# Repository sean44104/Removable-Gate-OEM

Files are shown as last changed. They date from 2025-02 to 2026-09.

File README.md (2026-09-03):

# Removable-Gate-OEM

Removable Gate OEM is a project [based on my previous work](https://github.com/sean44104/Removable-Gate-GCC) designed to bring the removable gate system to OEM Gamecube Controller shells in the form of a small DIY kit

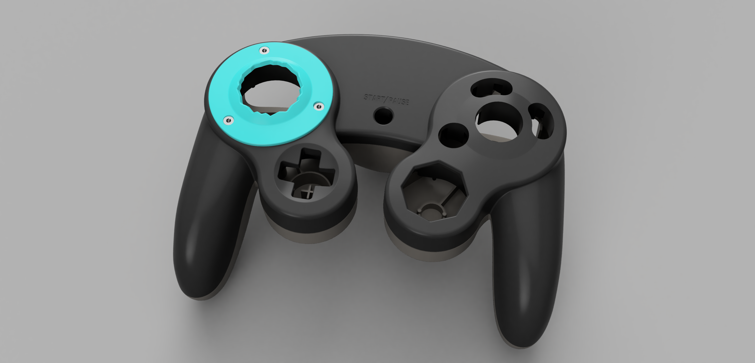
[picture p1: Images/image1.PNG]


This release contains STL, STEP, and F3D files for each part of the project. The STLs are high resolution and ready to be resin printed. You can import the F3D file into fusion360, or the STEP files into any other CAD program you like to make changes to the design as you see fit! The files feature 5 unique gateplate designs, each with their own different number of notches for you to experiment with. Additionally, the files also include what I call a **ThreadHolder** and a **DrillJig**. The ThreadHolder is a piece that will slide under the control stick area of the GCC front shell. It has slots inside that will hold the metal threads permanently inside of the shell. When you put a gateplate onto the front of your controller, the gateplate will screw into these threads and hold it firmly in place!

This project requires modification of the OEM Gamecube Controller front shell in order to fit and function. A section of the shell first needs to be removed, and then 3 holes need to be drilled into the shell. These holes require a 3/16 inch drill bit. The DrillJig is a piece that slides under the control stick area of the GCC, just like the ThreadHolder, and shows you exactly where to drill so that you can put the drill holes in the exact perfect spot. After you are done drilling, the DrillJig is to be removed from the controller and replaced by the ThreadHolder, the permanent piece that goes in that spot for the mod to work. You can reuse the DrillJig to drill holes in multiple controller shells. **Use the DrillJig after removing the gate area of the front shell and before installing the ThreadHolder!**

### Relevant Links:

Gateplate Screws: https://www.mcmaster.com/90236A105/

Gateplate Threads: https://www.mcmaster.com/90363A110/

Where to Purchase the 3D Printed Parts: https://jlc3dp.com

The Gateplate Screws are T6 Torx Screws. If you do not have a T6 Torx Screwdriver, [you can buy them anywhere](https://www.amazon.com/Screwdriver-TECKMAN-Controller-Mainboard-Electronic/dp/B08998GX65/ref=asc_df_B08998GX65)

YouTube Video going over the concept and explaining how the kit works with visuals:
https://youtu.be/-zyUboVVk4A

Video Build Guide: https://youtu.be/2FYZF3ZB4hE

Parametric Notch Builder Tool: https://www.printables.com/model/1191100-parametric-notch-builder-tool-for-oem-stubby-gatep

CarVac FDM File Set & Additional Parametric Gateplates: https://www.printables.com/model/1504464-oem-gamecube-controller-notched-gateplates/files

This design is based on, and uses the OEM GCC step file collection made by GearHawkStudios

### Optional PTFE Upgrade:

I have found that when using resin printed gateplates, especially with resin casted stick caps, there can be more friction on the gate against the stick than on a standard controller. I highly recommend applying a layer of PTFE tape around the neck of your stick cap. This small mod can help improve the feel of your gate and enhance the durability of your controller. 

PTFE Tape: https://www.mcmaster.com/6305A51/

Installation Guide: https://youtu.be/KtZ6UY_qpAE

### Removable Gates and Notched Gateplates
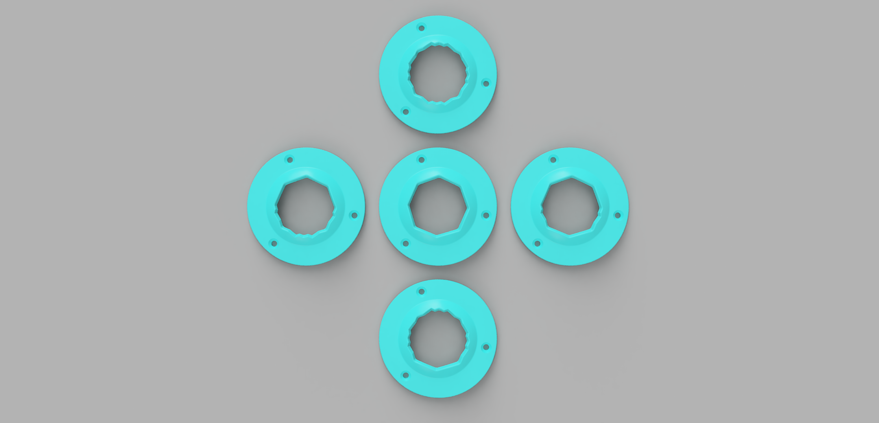
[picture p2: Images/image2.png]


### DrillJig (left) and ThreadHolder (right)
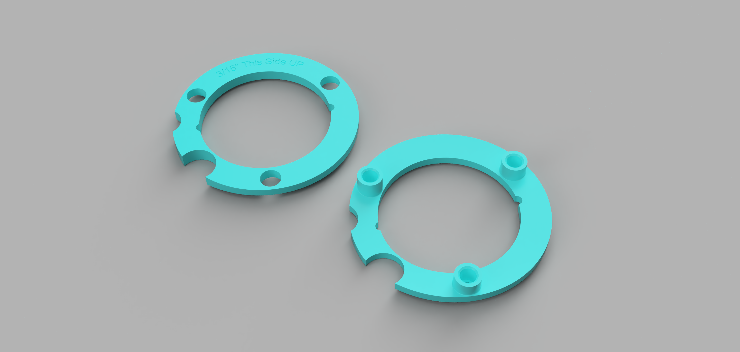
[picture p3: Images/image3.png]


### Inside View of the ThreadHolder System
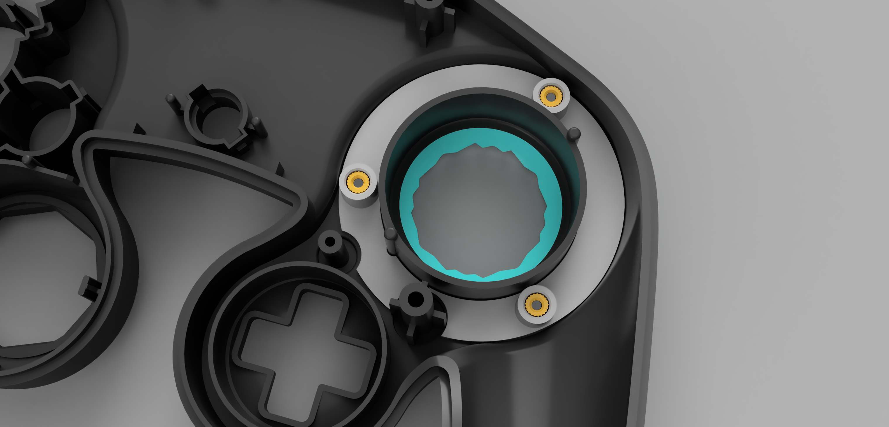
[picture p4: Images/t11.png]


# Parametric Notch Builder
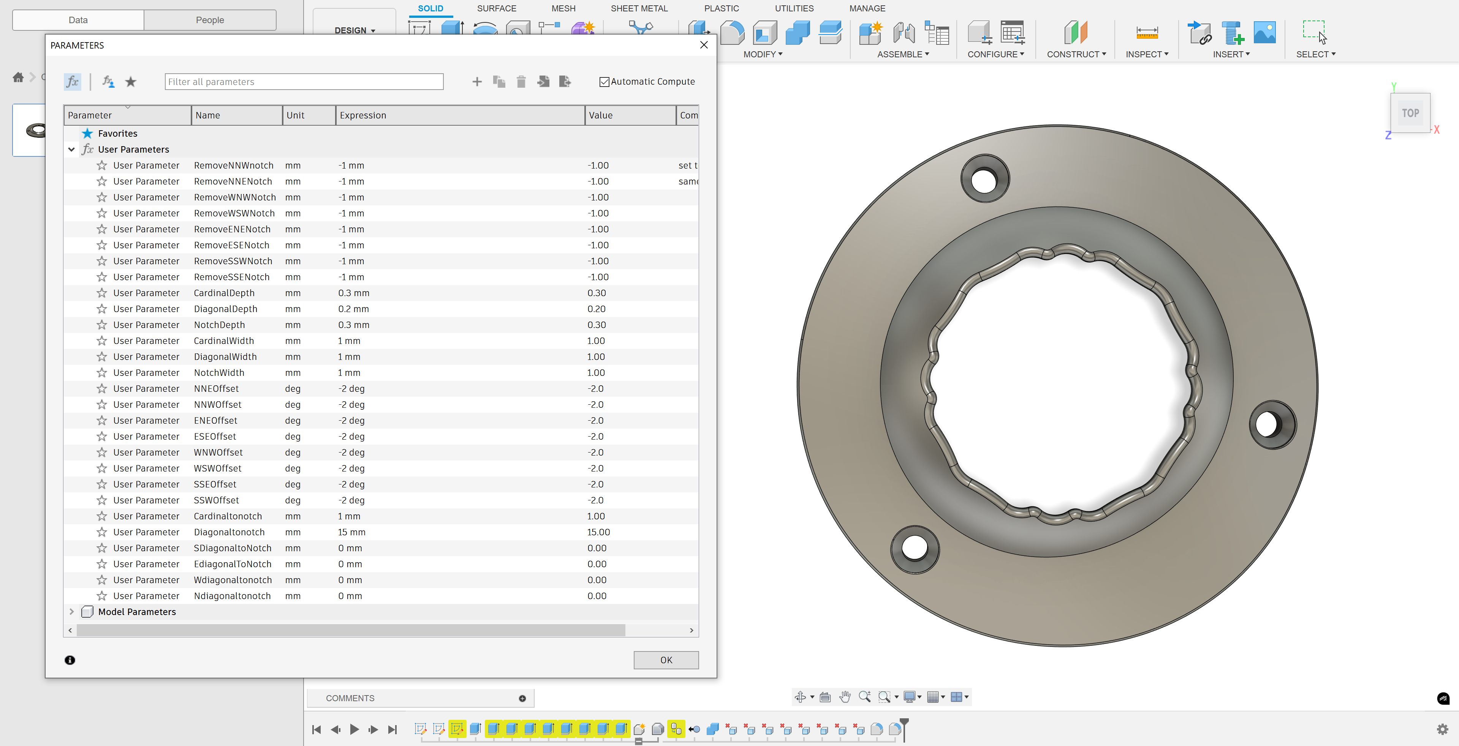
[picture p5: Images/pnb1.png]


The [Parametric Notch Builder Tool](https://www.printables.com/model/1191100-parametric-notch-builder-tool-for-oem-stubby-gatep) allows you to input values into a menu and slightly adjust the geometry of a Notched Gateplate. With this, you can remove notches, adjust notches, move notches around the gate, and adjust the overall shape and profile. This lets you get very specific with your Gateplate design and allows you to do things that are character specific on a whim.
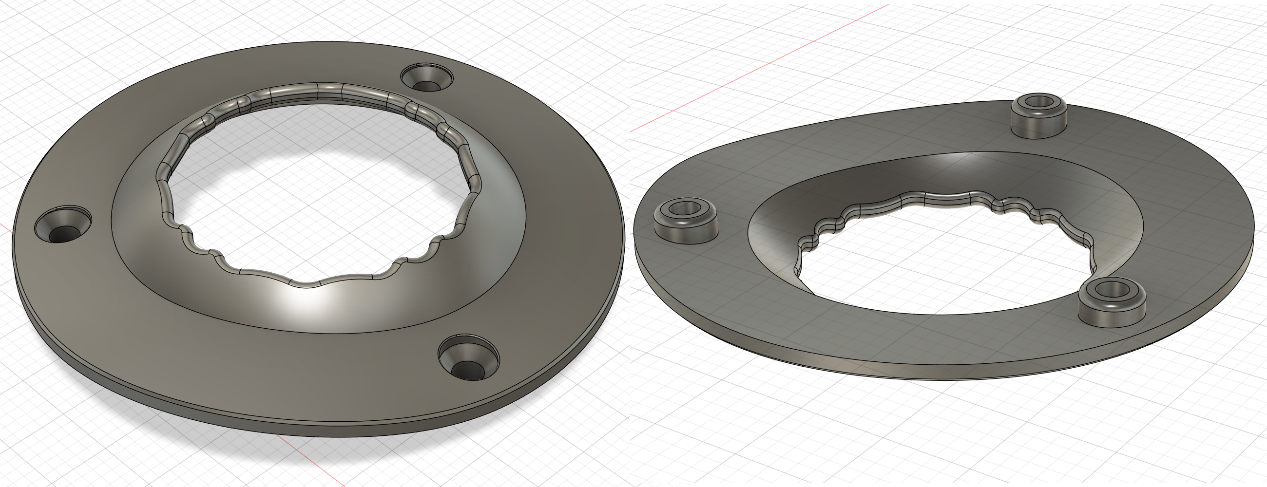
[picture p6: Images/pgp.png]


Personally, I prefer the smooth profile of the parametric notched gateplate over harsher notched gateplates included in the standard release. I have included some sample gateplates made using this tool, and I encourage you to try it out and create your own!

# Removable Gate OEM Installation Tutorial:
<details>
  <summary>Click to expand</summary>

## Step 1
The first thing you need to do is remove the gate material from the front shell. Remove the entire lifted circular section of the control stick gate, shown here in green. Cut off the entire lifted dome until it is flat with the rest of the front shell's surface. You can use a dremel to cut it off and then sand down the excess. Do not go deep into the shell, remove any of the inside, or take out the cylinder that extends down into the shell. Here is a front and side profile of what is to be removed:
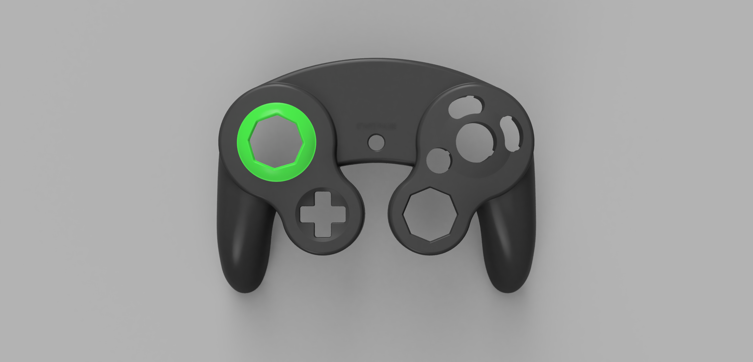
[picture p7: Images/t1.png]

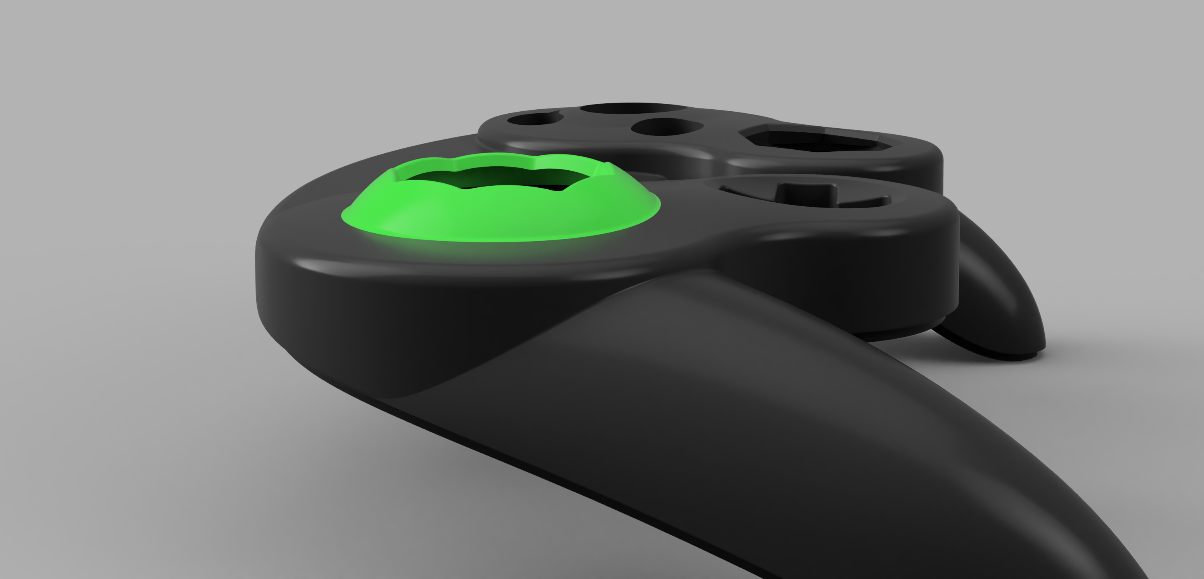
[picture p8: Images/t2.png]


**Your shell should look like this after you are finished**
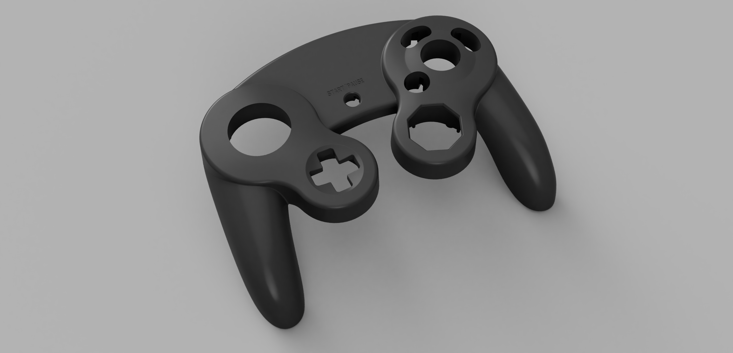
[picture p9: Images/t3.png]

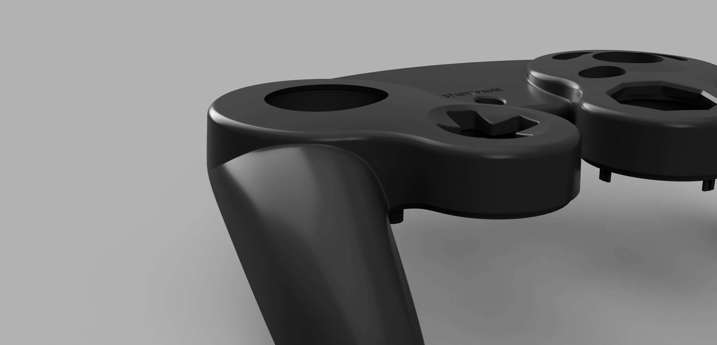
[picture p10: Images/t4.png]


## Step 2
Next, you are going to use the DrillJig. Slide the jig into the back of the front shell so that the curved side is going down into the controller and the flat side is facing up as shown. Now, use a 3/16 inch drill bit to remove the material shown here in green:
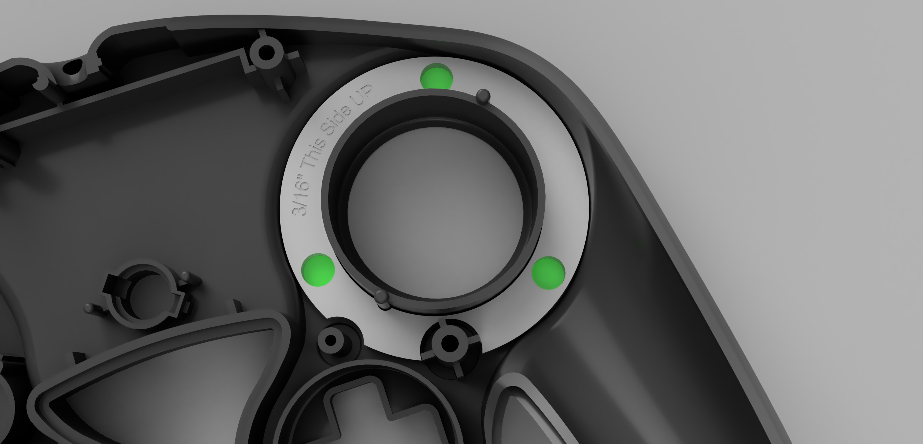
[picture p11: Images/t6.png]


Once you are finished drilling it should look like this:
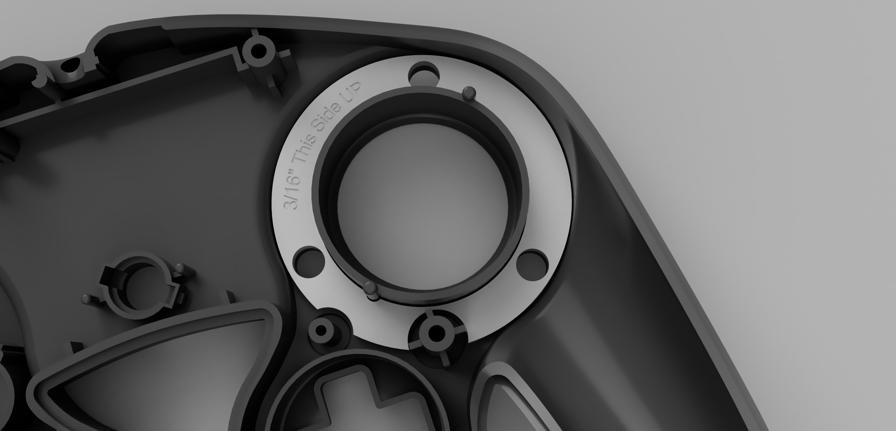
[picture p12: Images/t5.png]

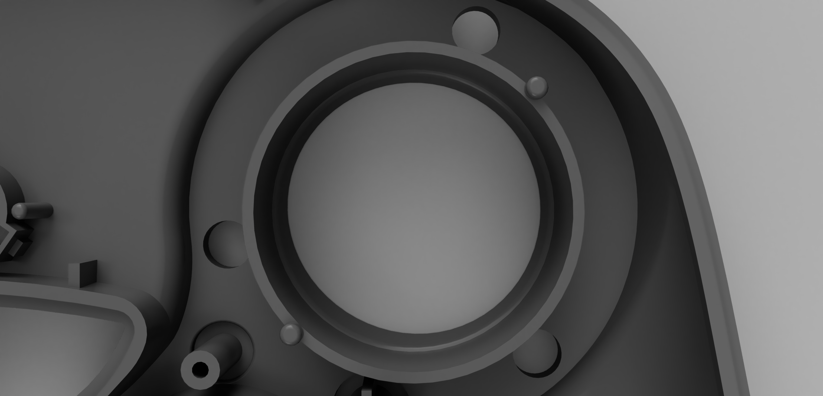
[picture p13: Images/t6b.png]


Here is a view from the other side:
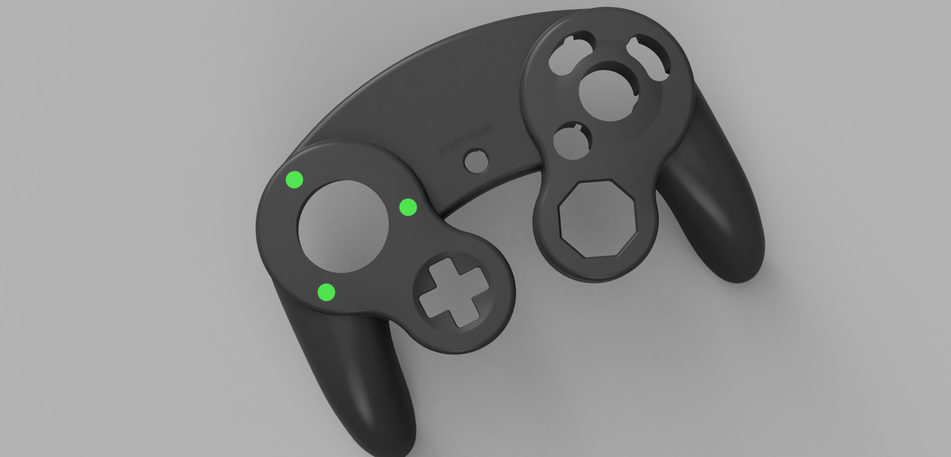
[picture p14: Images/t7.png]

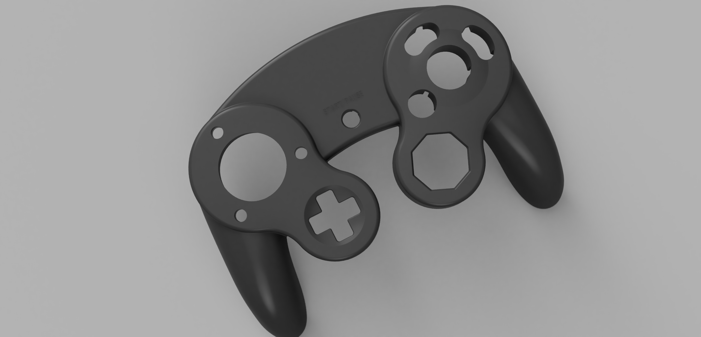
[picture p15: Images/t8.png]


## Step 3
Now, you are going to install the ThreadHolder. Remove the DrillJig from the controller shell and apply a small amount of glue to the flat top surface of the ThreadHolder. Then, you are going to slide it into the back of the front shell, just like the DrillJig, shown here:
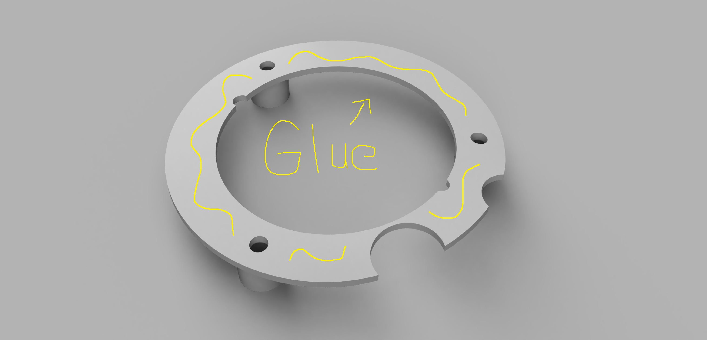
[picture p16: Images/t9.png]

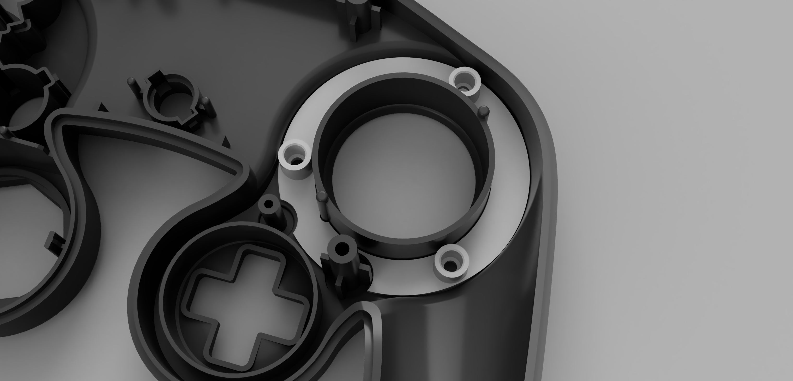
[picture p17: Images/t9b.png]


Make sure to firmly press the ThreadHolder in and push it down so that the entire piece makes good contact with the back of the controller front shell

## Step 4
Take your [thread pieces](https://www.mcmaster.com/90363a110/) and push them into the containers of the ThreadHolder until they are all the way in, as shown. This may be a tight friction fit, so you can use a screwdriver to push them in by applying pressure to the center of the thread piece.
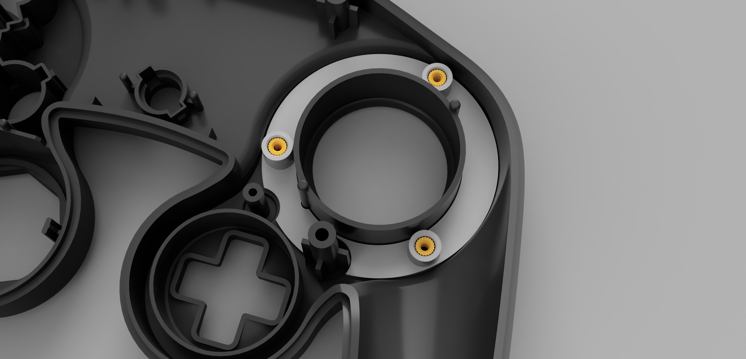
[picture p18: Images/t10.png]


These thread pieces are designed to expand out when [the screw](https://www.mcmaster.com/90236A105/) is threaded inside of them, embedding themselves into the ThreadHolder and locking them inside of there permanently. I recommend that for the first time, you put the screws in upside-down like so. This way the threads can be expanded securely and will not fall out.
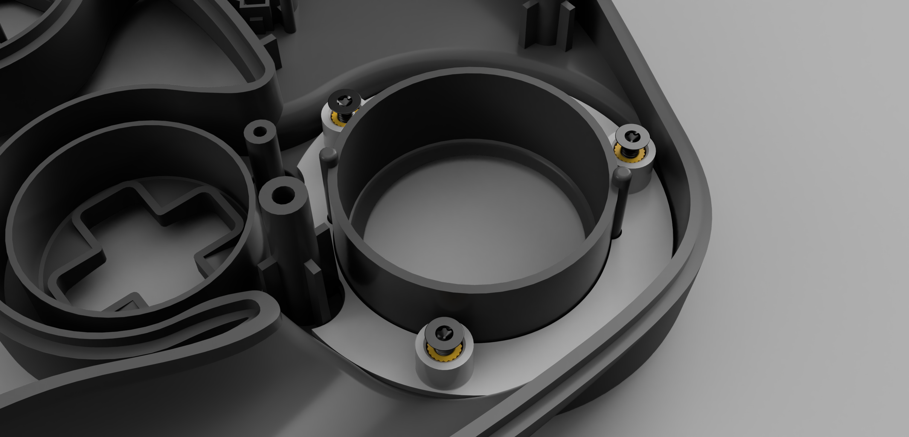
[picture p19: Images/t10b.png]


## Step 5
You are basically done now! Remove the upside-down screws from their thread pieces. The front shell is complete. You can now take a Gateplate and place it onto the front face of your Gamecube Controller front shell. It has three pegs underneath it, which will slot nicely into the holes that you drilled. Now, just insert a screw into each of the three holes on the gateplate surface and they will go through the gateplate, through the front shell, and thread into the metal inserts inside of the ThreadHolder. It will look like this when you are done and everything is fully installed:
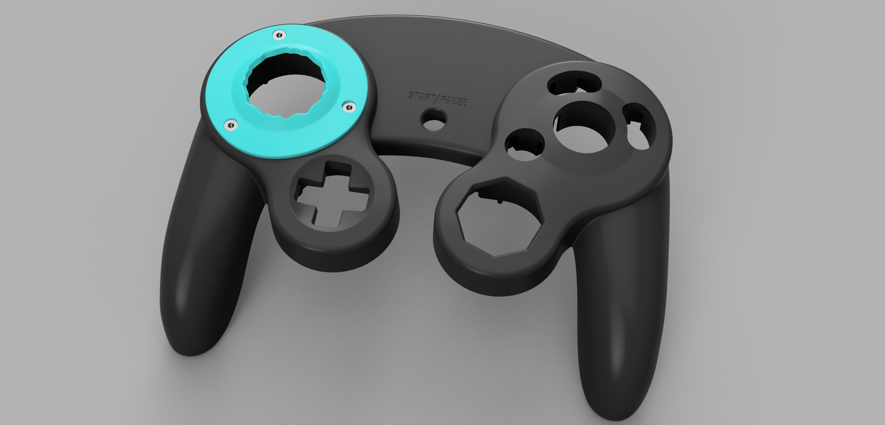
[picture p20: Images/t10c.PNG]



Now, you can assemble your controller. You will be able to remove and attach gateplates onto your controller while it is fully assembled. You do not have to take the controller apart whatsoever to remove or swap out a gateplate. Simply unscrew the Gateplate, remove the screws, and pull the Gateplate out.
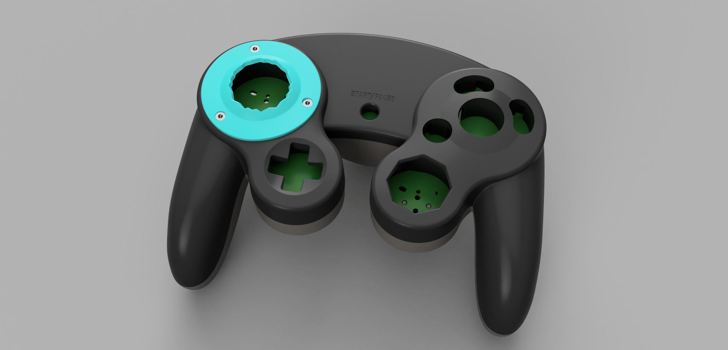
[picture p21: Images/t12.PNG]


The internal parts will stay in place and not fall out. Happy Modding!
</details>

# Optimal JLC3DP Part Settings, Prices, and Shipping:
<details>
  <summary>Click to expand</summary>

## Gateplates
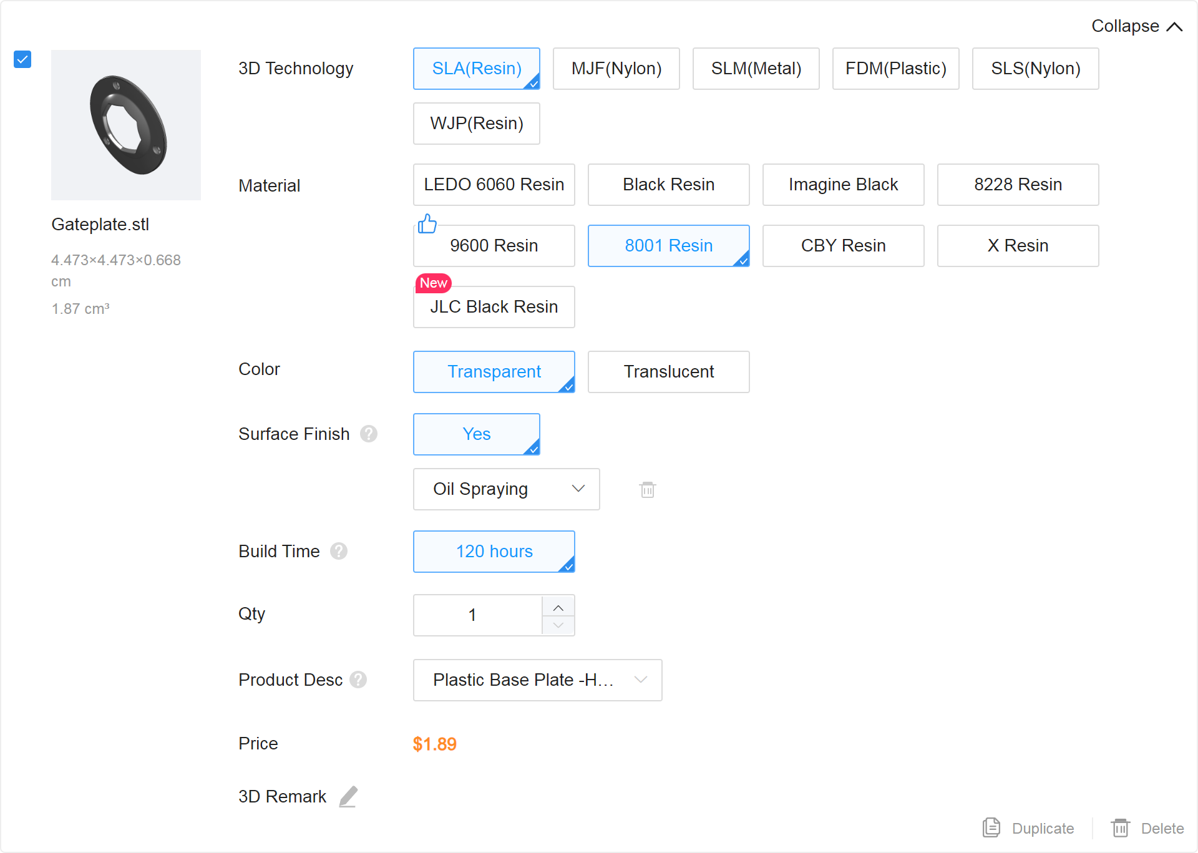
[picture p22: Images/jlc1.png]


8001 Transparent Oil Spray is the best material for the Gateplate because of its high hardness, low friction, and good dimensional stability. A Gateplate made of this material will feel the smoothest when it touches your control stick and most OEM ABS Plastic-like. It will be more consistent and have a more perfect shape than something like Black Resin. 8001 Transparent Oil Spray Resin does have an issue where it is slightly thicker than the rest of the materials. For this reason, I do not recommend it for internal parts where tolerances and clearance are a priority. But for the external Gateplate, its perfect.

## ThreadHolder
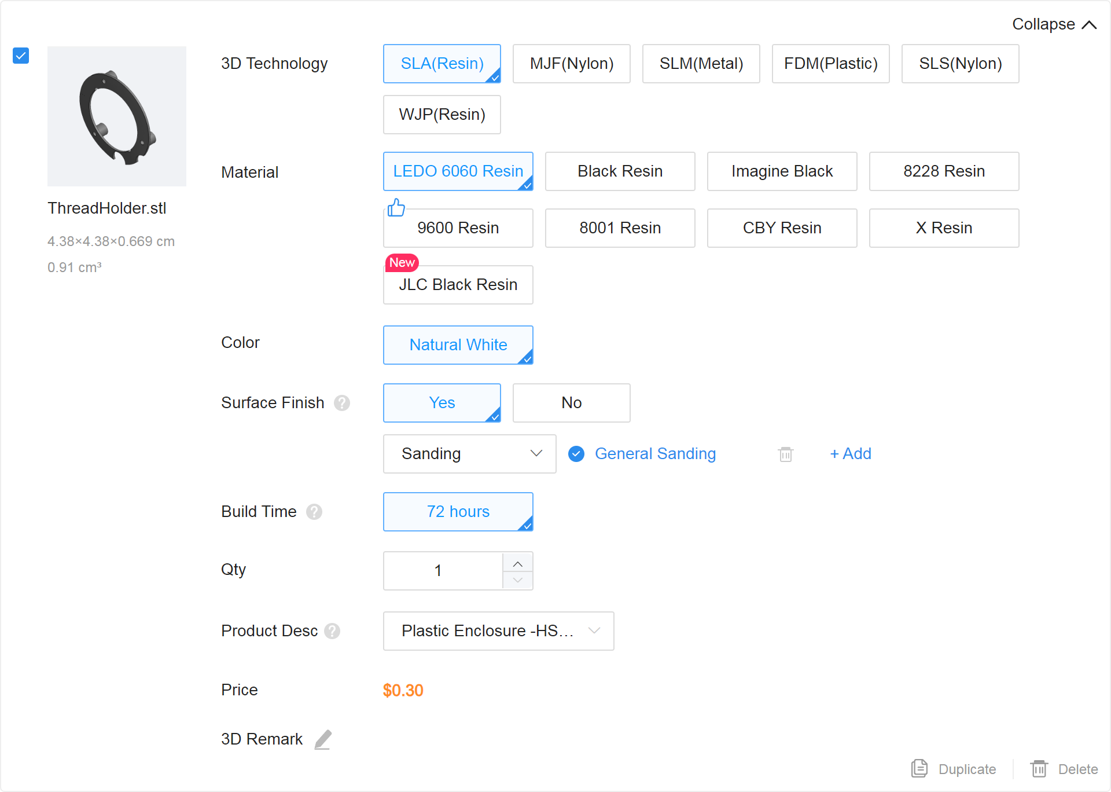
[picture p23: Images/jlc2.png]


LEDO 6060 is the least expensive resin on the website. It does not have the smoothness of 8001 Transparent Oil Spray or the highly detailed and accurate surface finish of Black Resin, but it is more dimensionally stable than Black Resin and does not have the extra thickness issue that 8001 has. For a precise part like the ThreadHolder, that also wont be seen from the outside very much at all, I believe LEDO 6060 is the best choice.

## DrillJig
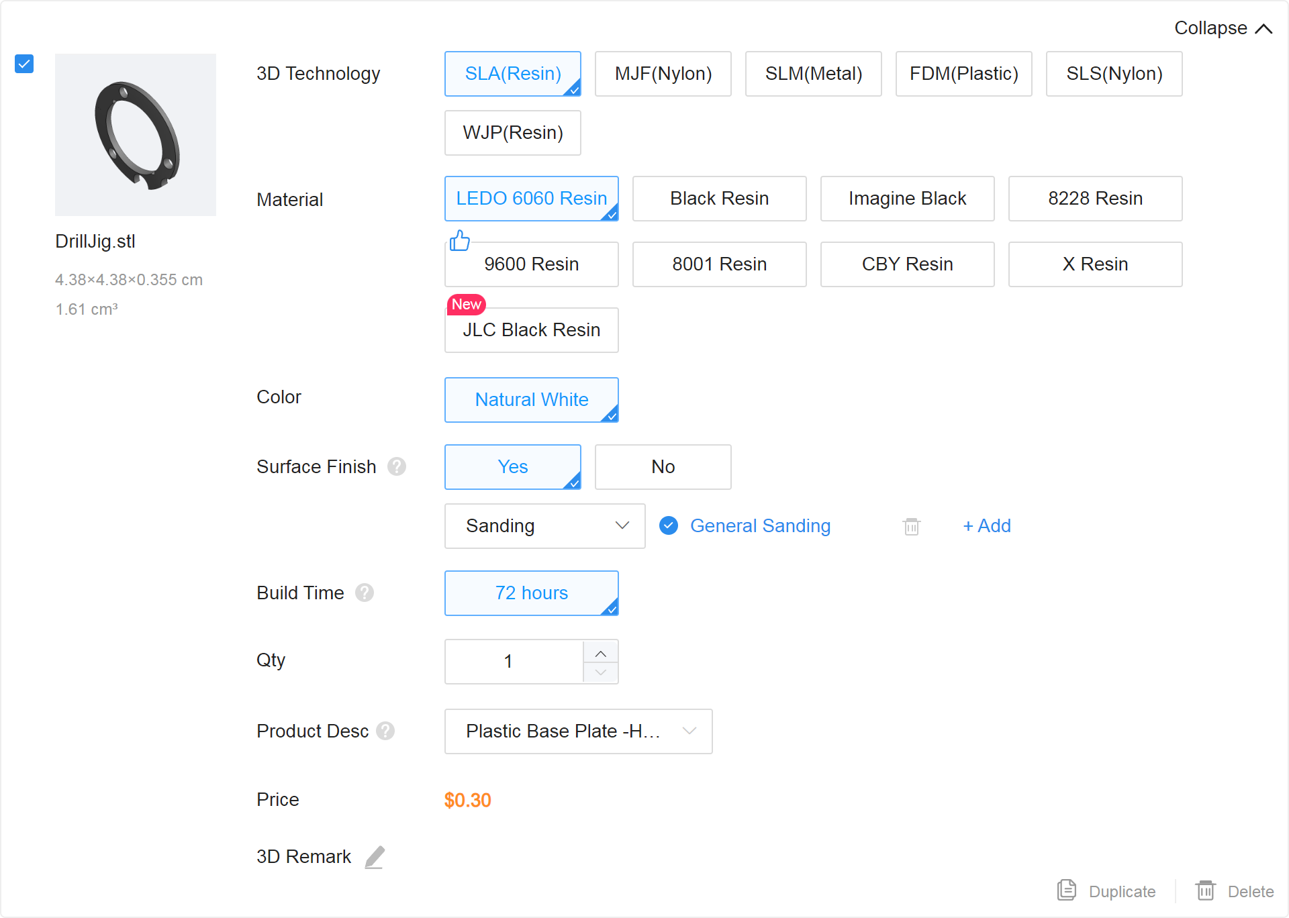
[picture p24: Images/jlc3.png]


I choose LEDO 6060 resin for the DrillJig for pretty much the same reason as I chose it for the ThreadHolder. The DrillJig is the only temporary piece in this kit. It is used to accurately drill your holes, and then it is either discarded or used again to make multiple shells. Because of this, it's material matters the least. Also, because of the DrillJig's completely flat surface, you could probably FDM print this part as well!

## Other Parts

While not explicitly part of this project, I do want to point out that *generally* the best and safest resin to print something in is actually Black Resin or JLC Black Resin. This resin type is smooth to the touch and has very high "resolution". It has a detailed, smooth, accurate surface that is much better than something like LEDO 6060. For general parts, such as buttons, shells, stick bases, or other small detailed parts, Black Resin is generally the way to go. If you want to guarantee that the part you order is MOST similar to the STL file that you designed and submitted, you should usually order parts in JLC Black Resin.

## Shipping

While you may notice that the prices for these individual parts can be very inexpensive, keep in mind that the shipping is usually where the majority of the cost is going to come from. While JLC3DP shipping can be relatively expensive, this does not mean that it is bad or that your parts will take months to get to you. From my experience, it takes about 2-3 weeks for an order to go from shipped to delivered. Usually around 10 days. Below are some prices and shipping estimates from JLC3DP. I would consider their information to be accurate. Even with the shipping cost included, you can obtain all of the 3D printed the parts needed for this kit for only about $20 - $30

<details>
  <summary>Click to expand</summary>

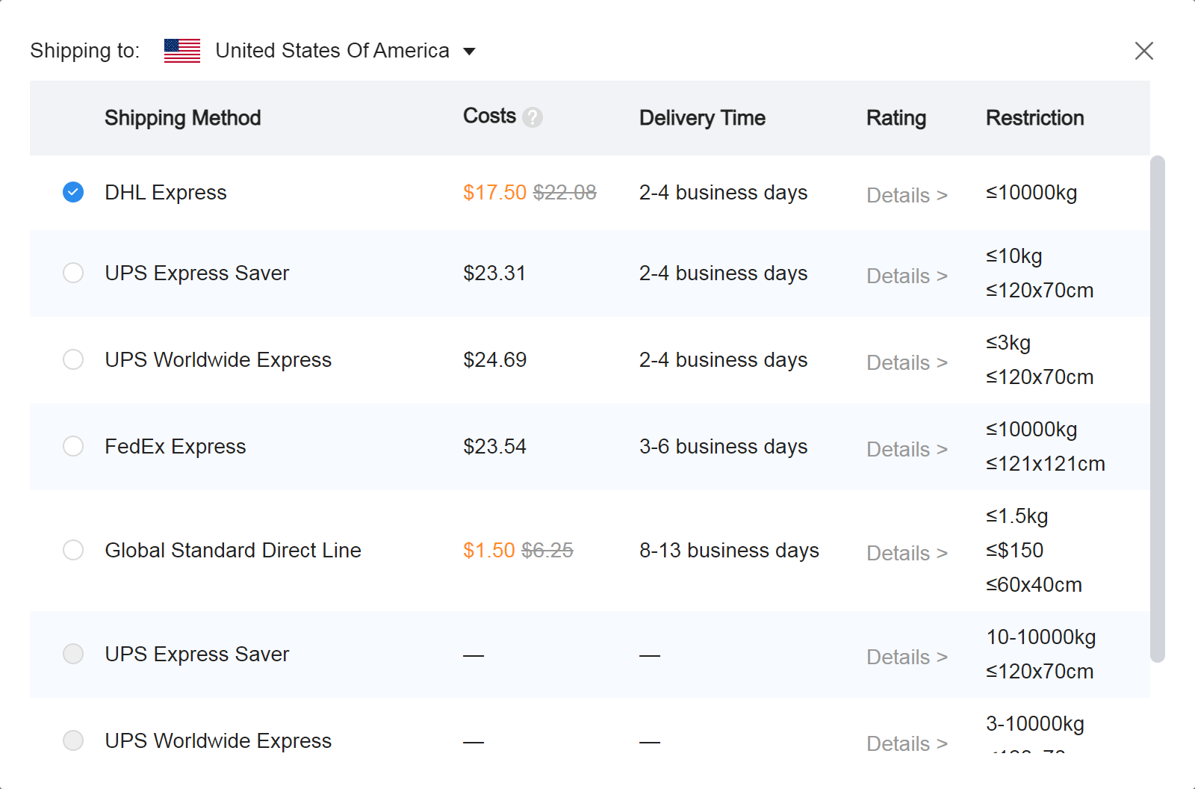
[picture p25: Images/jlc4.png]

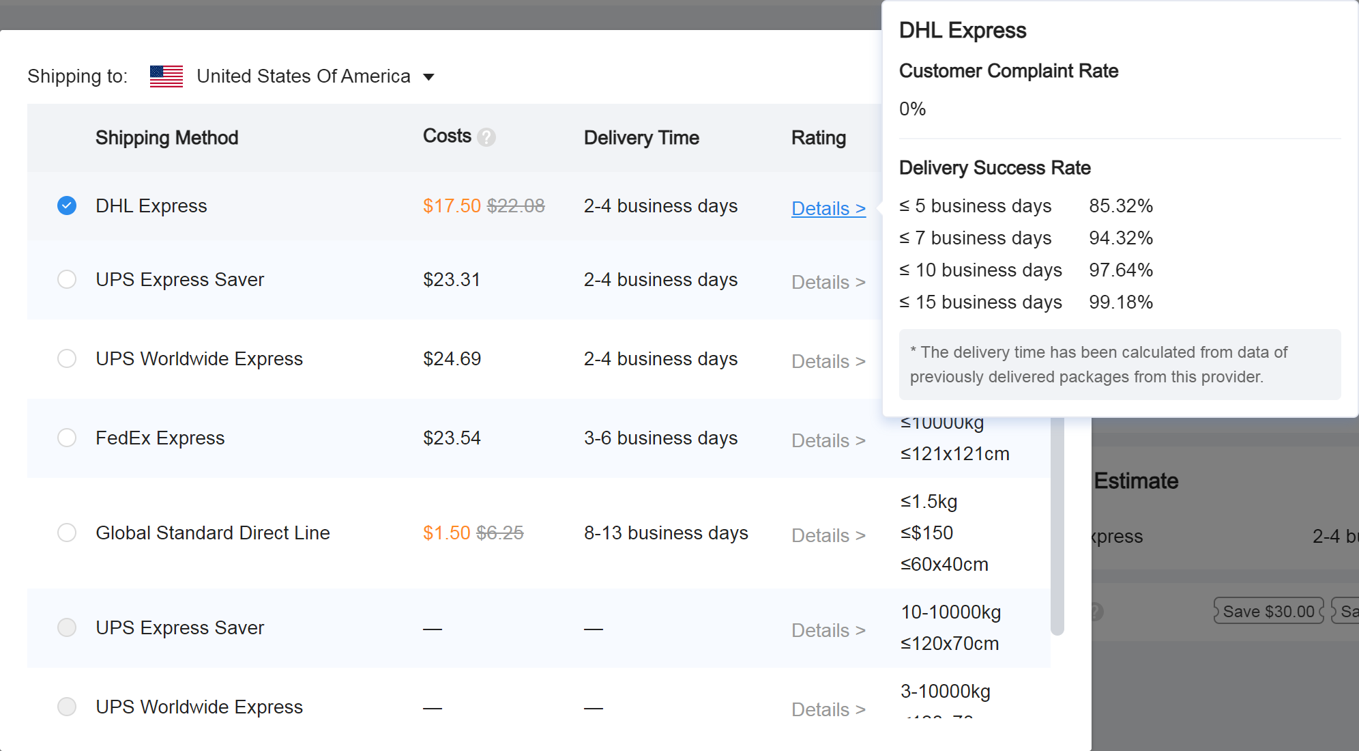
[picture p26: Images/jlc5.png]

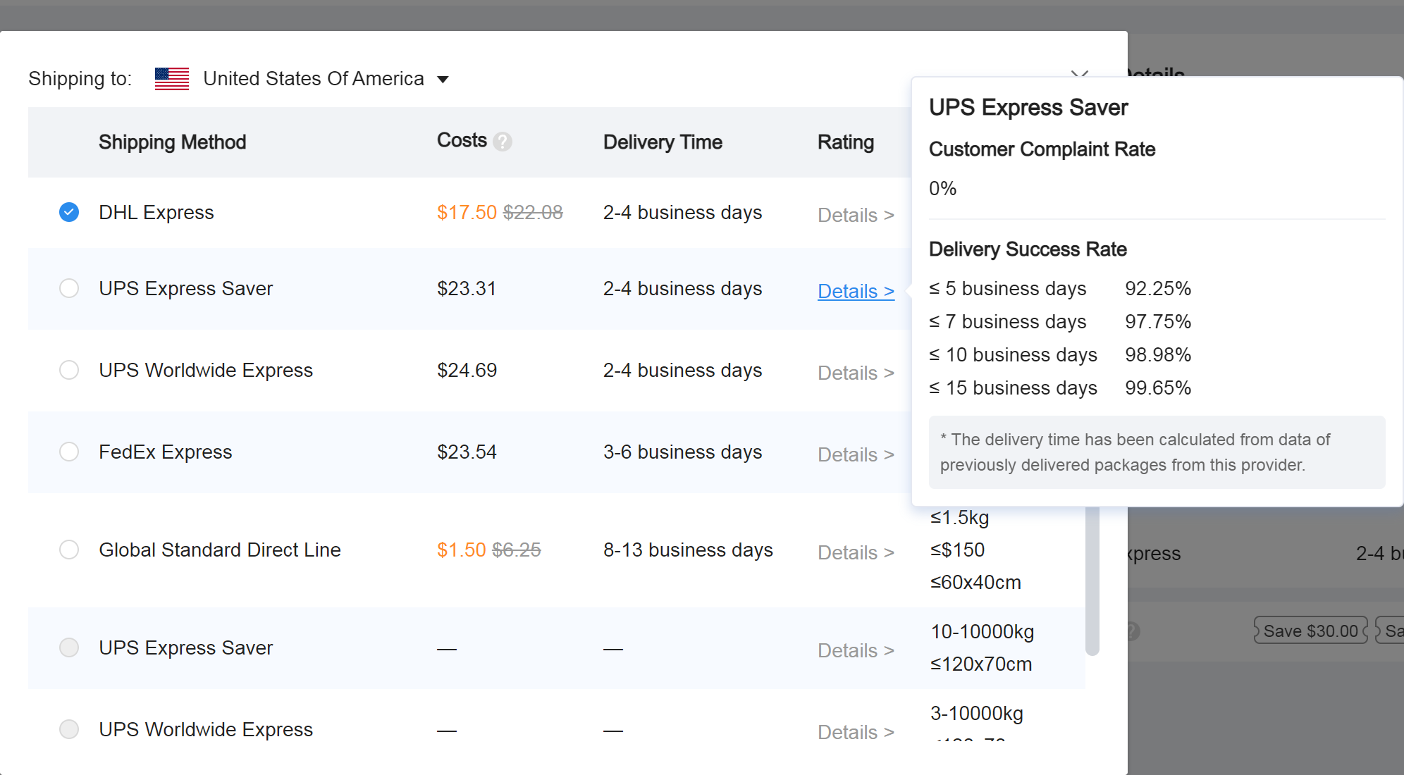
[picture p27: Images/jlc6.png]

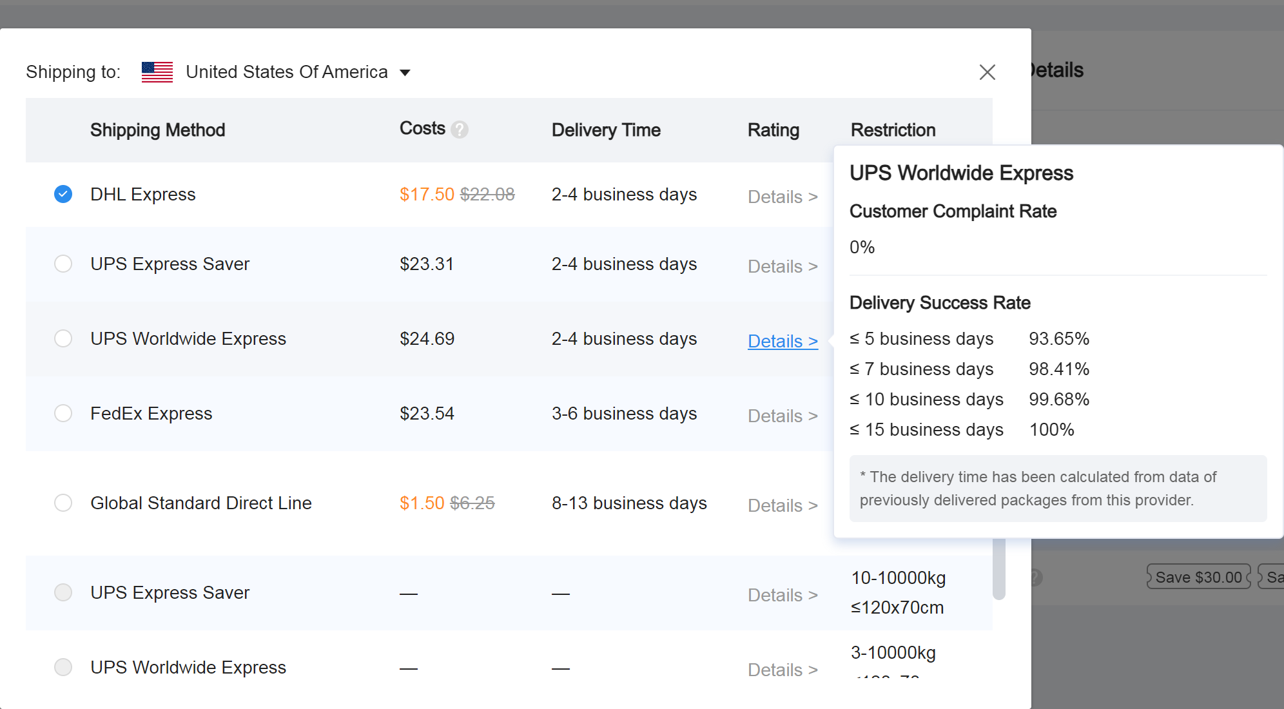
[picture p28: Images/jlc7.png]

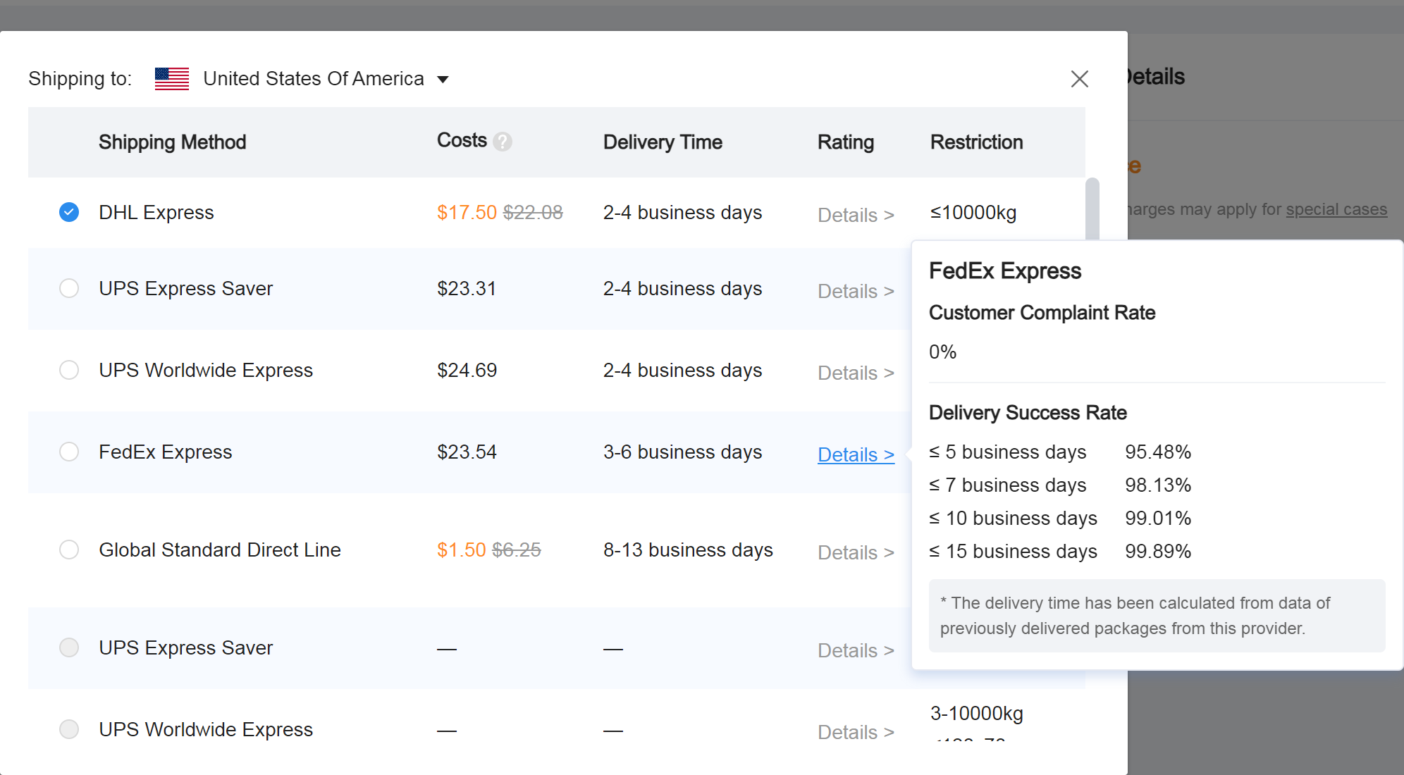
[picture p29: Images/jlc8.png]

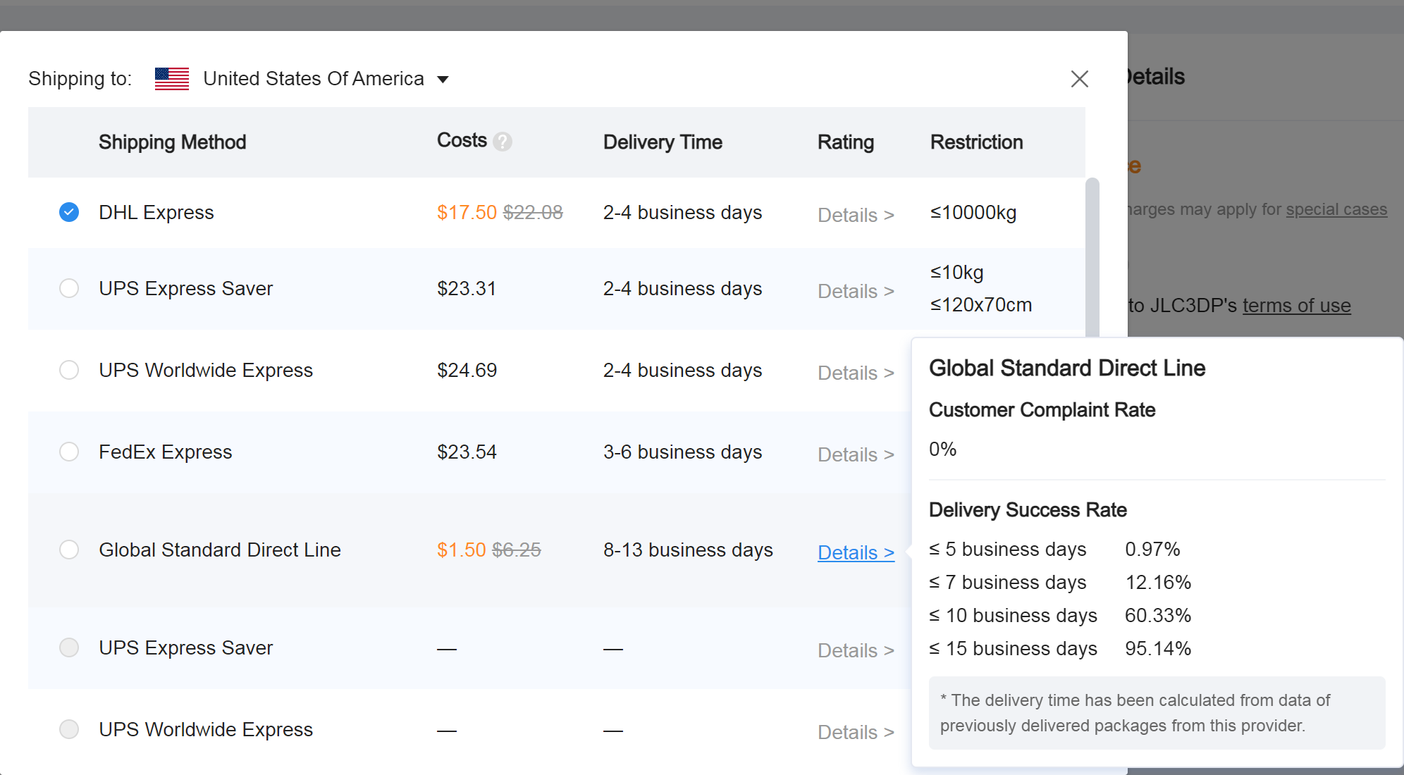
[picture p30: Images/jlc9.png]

</details>

</details>

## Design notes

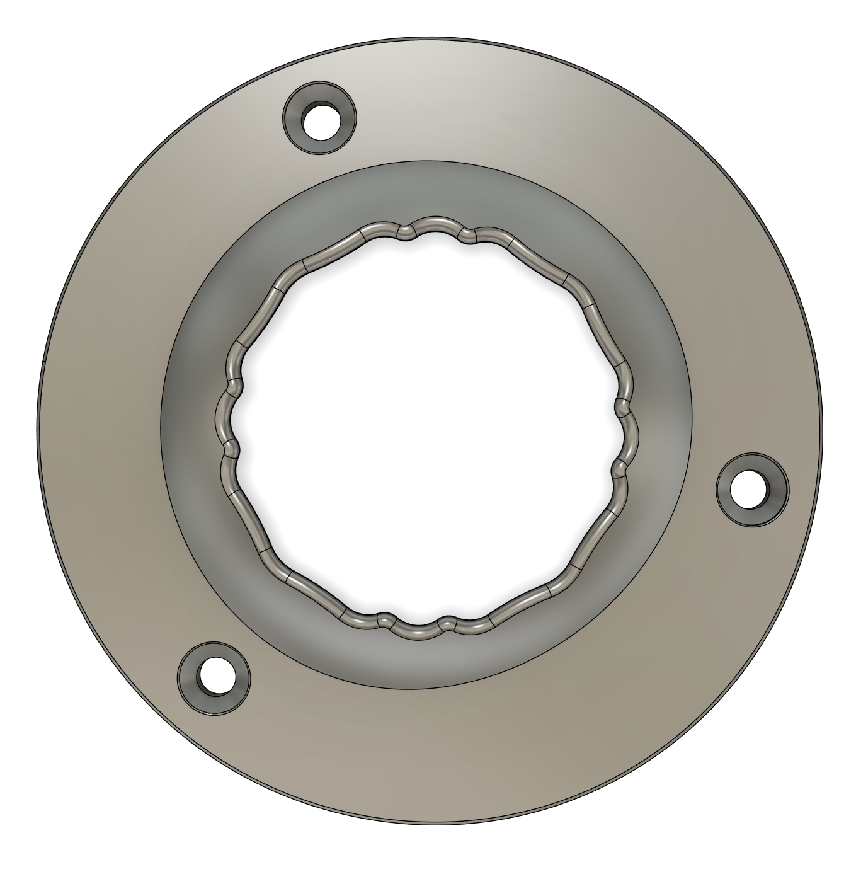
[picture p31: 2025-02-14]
Images/pnb2.png

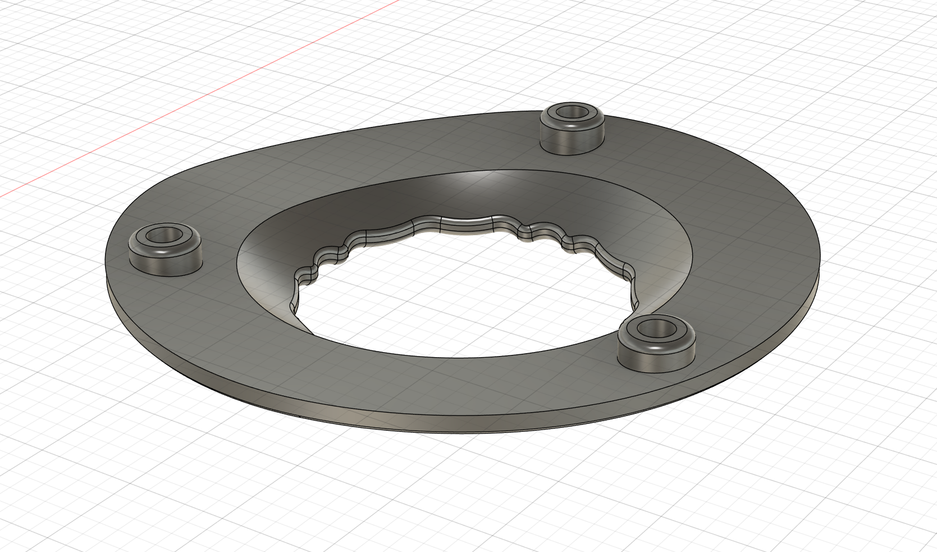
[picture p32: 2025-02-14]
Images/pnb4.png

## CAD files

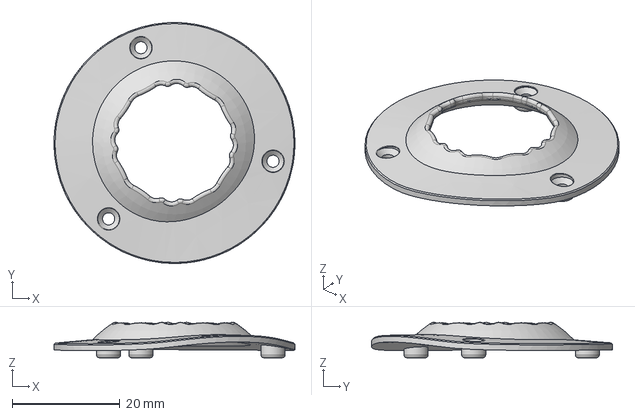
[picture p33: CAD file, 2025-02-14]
ParametricGateplates/STEPs/ParametricGateplateFullWDFF.step
44.7 x 44.7 x 6.60 mm

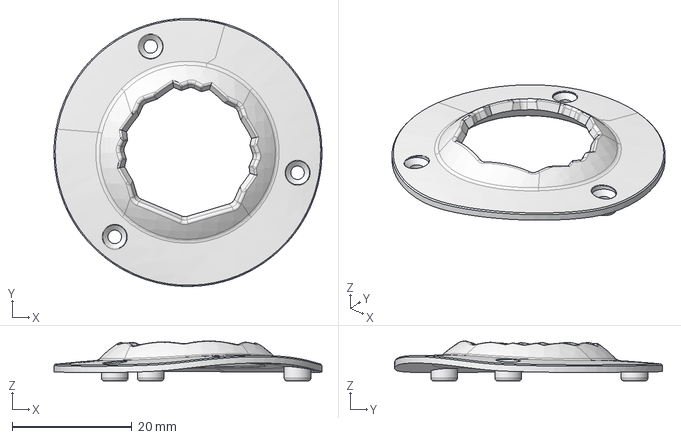
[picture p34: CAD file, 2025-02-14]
STEPs/gateplates/Gateplate-FullNoMinWD.step
44.7 x 44.7 x 6.68 mm

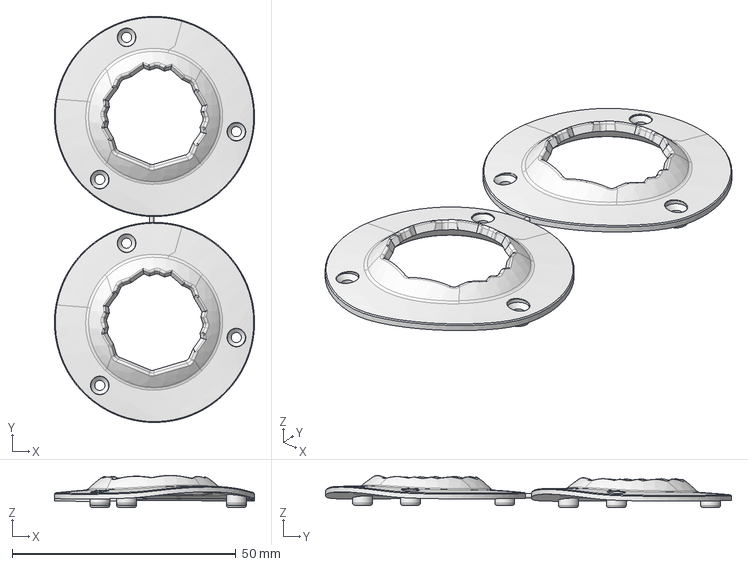
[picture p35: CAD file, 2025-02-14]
NestedFiles/STEPs/DoubleGateplate-FullNoMinWD.step
44.7 x 90.7 x 7.18 mm

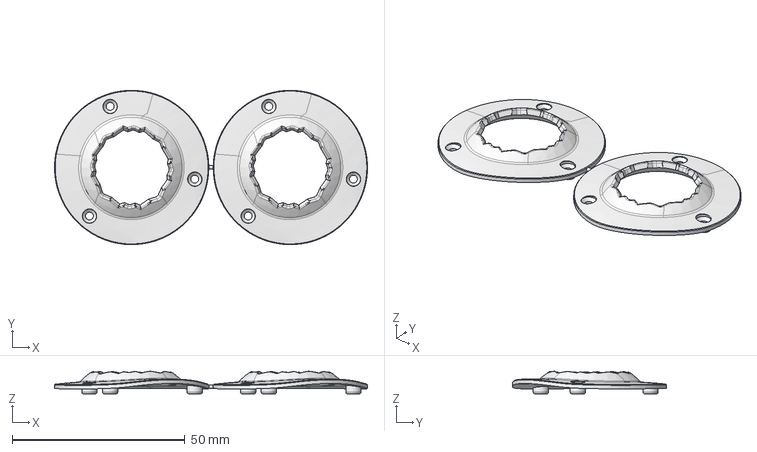
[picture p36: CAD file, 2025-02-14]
NestedFiles/STEPs/DoubleGateplate-FullWDFF.step
90.7 x 44.7 x 6.56 mm

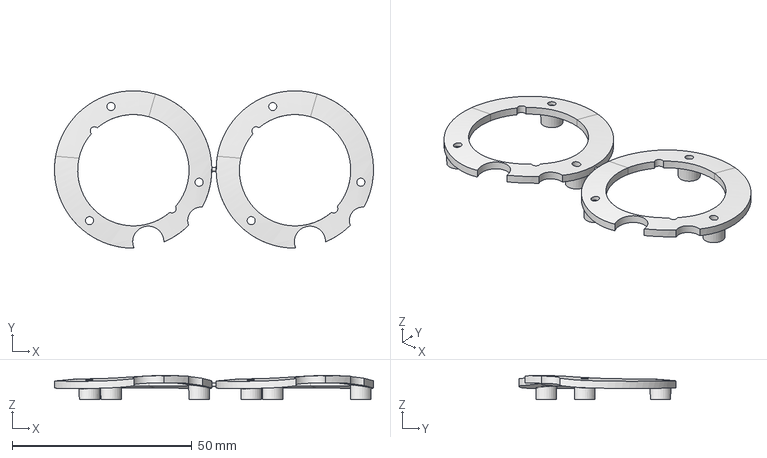
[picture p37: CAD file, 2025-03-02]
NestedFiles/STEPs/DoubleThreadHolder.step
88.8 x 43.8 x 6.68 mm

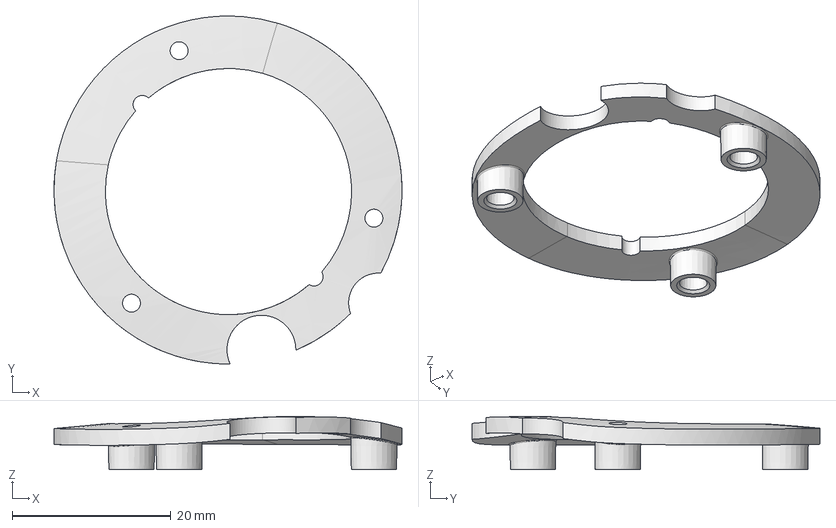
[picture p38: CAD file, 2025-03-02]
STEPs/ThreadHolder.step
43.8 x 43.8 x 6.68 mm

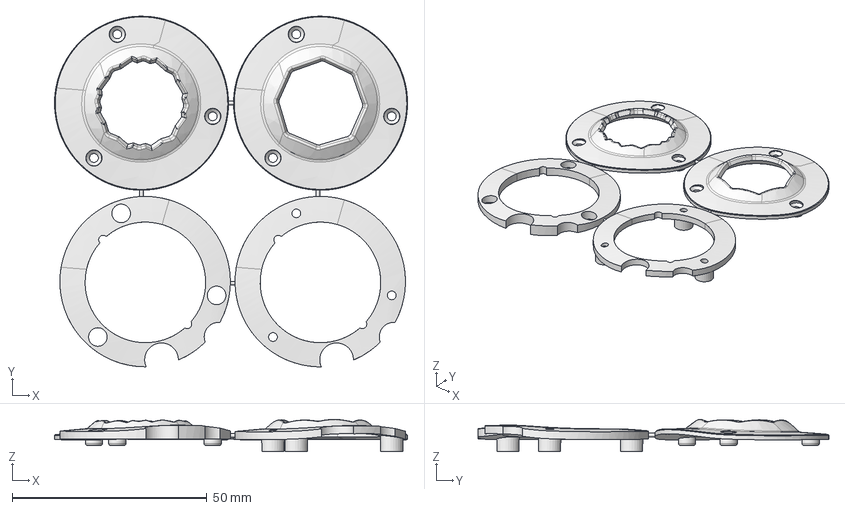
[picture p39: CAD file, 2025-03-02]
NestedFiles/STEPs/starterkit.step
90.7 x 90.1 x 8.25 mm

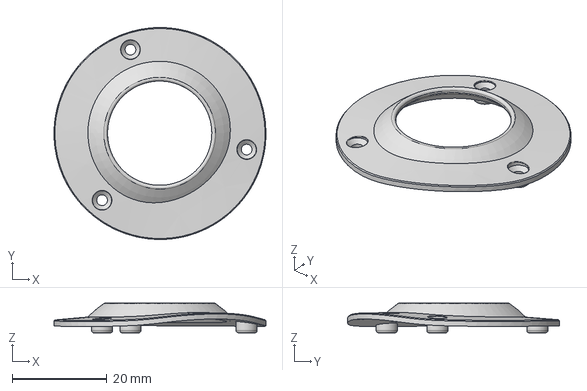
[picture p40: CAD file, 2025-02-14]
ParametricGateplates/STEPs/ParametricGateplateRounded.step
44.7 x 44.7 x 6.27 mm

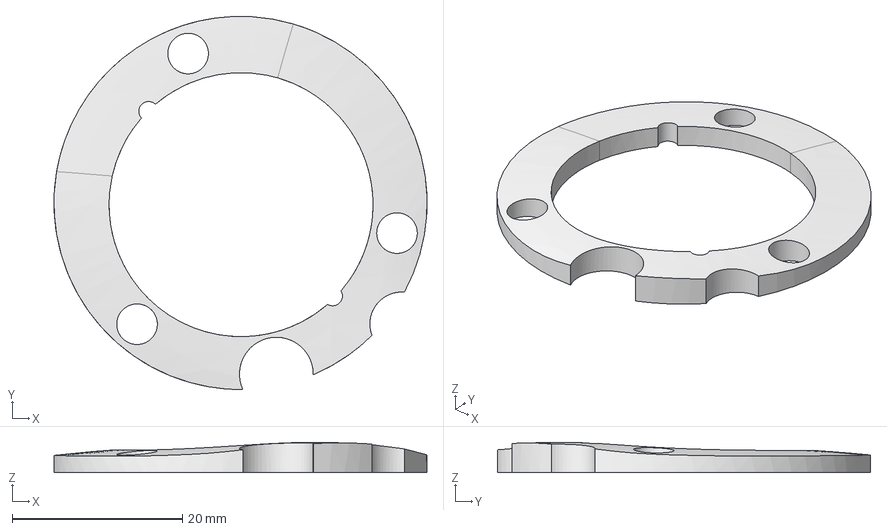
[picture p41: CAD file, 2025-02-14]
STEPs/DrillJig.step
43.8 x 43.8 x 3.55 mm

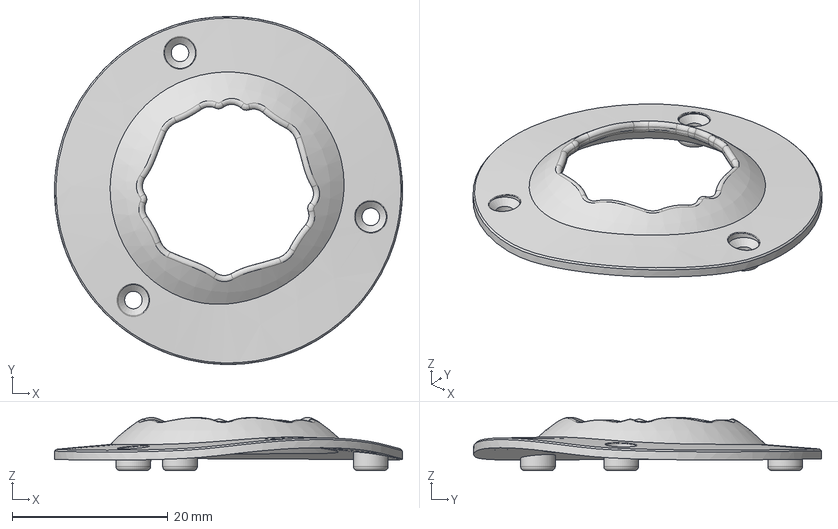
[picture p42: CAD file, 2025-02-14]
ParametricGateplates/STEPs/ParametricGateplateWDSlightDI.step
44.7 x 44.7 x 6.81 mm

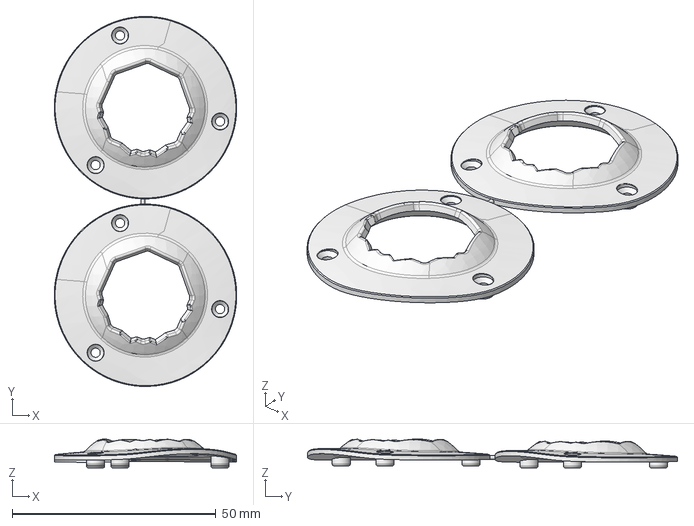
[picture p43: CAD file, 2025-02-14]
NestedFiles/STEPs/DoubleGateplate-MaxMinWD.step
44.7 x 90.7 x 7.10 mm

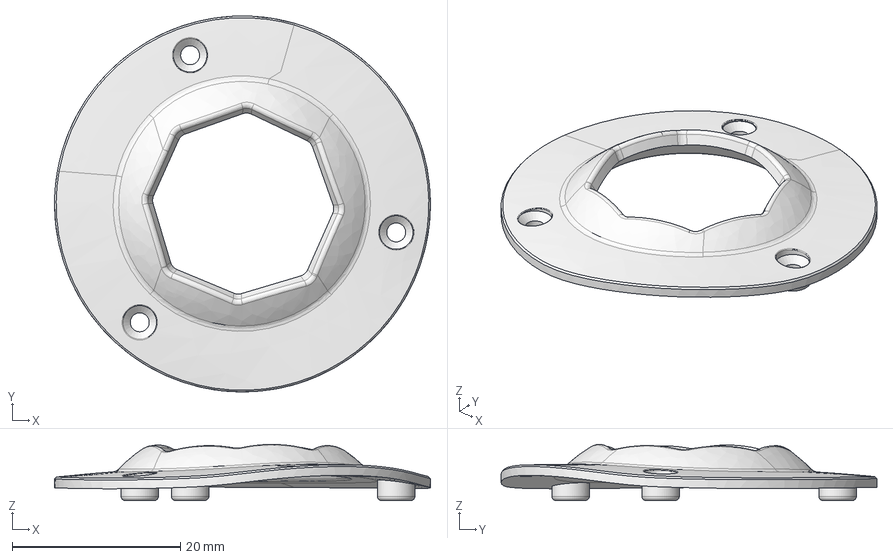
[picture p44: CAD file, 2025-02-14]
STEPs/gateplates/Gateplate.step
44.7 x 44.7 x 6.67 mm

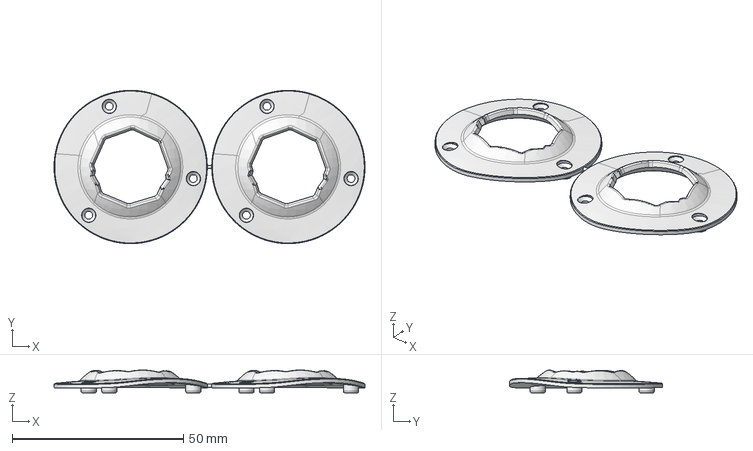
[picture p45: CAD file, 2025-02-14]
NestedFiles/STEPs/DoubleGateplate-MaxWD.step
90.7 x 44.7 x 6.68 mm

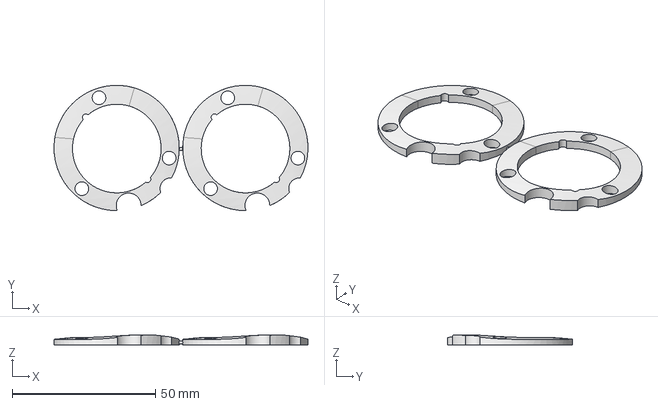
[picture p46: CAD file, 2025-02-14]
NestedFiles/STEPs/DoubleDrillJig.step
88.8 x 43.8 x 3.55 mm

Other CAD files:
STEPs/gateplates/Gateplate-FullWDFF.step
STEPs/gateplates/Gateplate-MaxWD.step
STEPs/gateplates/Gateplate-MaxMinWD.step
NestedFiles/STEPs/DoubleGateplate.step
NestedFiles/STLs/DoubleDrillJig.stl
NestedFiles/STLs/DoubleGateplate-MaxWD.stl
NestedFiles/STLs/DoubleThreadHolder.stl
STLs/DrillJig.stl
STLs/ThreadHolder.stl

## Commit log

2025-02-14 you can use these files to save some money
    [DoubleDrillJig.step, DoubleDrillJig.stl, DoubleGateplate-FullNoMinWD.step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]
2025-02-14 added parametric notch builder and gateplates
    [ParametricGateplateFullWDFF.step, ParametricGateplateRounded.step, ParametricGateplateWDSlightDI.step]
